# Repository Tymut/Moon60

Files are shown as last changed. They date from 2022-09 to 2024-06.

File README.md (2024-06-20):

# Moon60

---

Moon60 is is a split keyboard with 4x6 column staggered keys, 5 thumb keys and 1 extra key. This was school project related with hobby and evolved into fully functional device.

- Pro micro controller
- MX and Choc compatible, hotswap
- 128x32 OLED
- TRRS connection between sides
- Optional tenting supported by M12 screws
- Reversible PCB

**Firmware:** https://github.com/Nx0dle/qmk_firmware

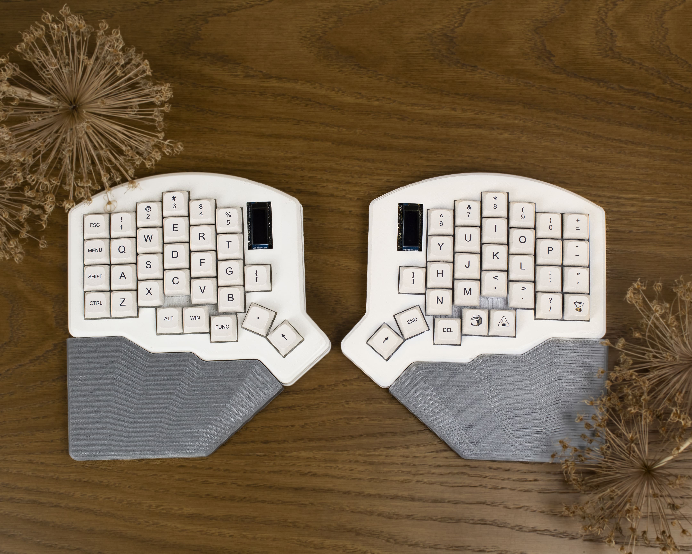
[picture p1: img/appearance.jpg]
moon60 appearance


Moon60 layout was inspired by hands scans from Ergopad (<https://github.com/pashutk/ergopad>) for matrix visualization. Scans were taken from 20 people and merged into subgroups.

Case for this keyboard is designed only for MX style switches (for now)

---

## Hand scans examples

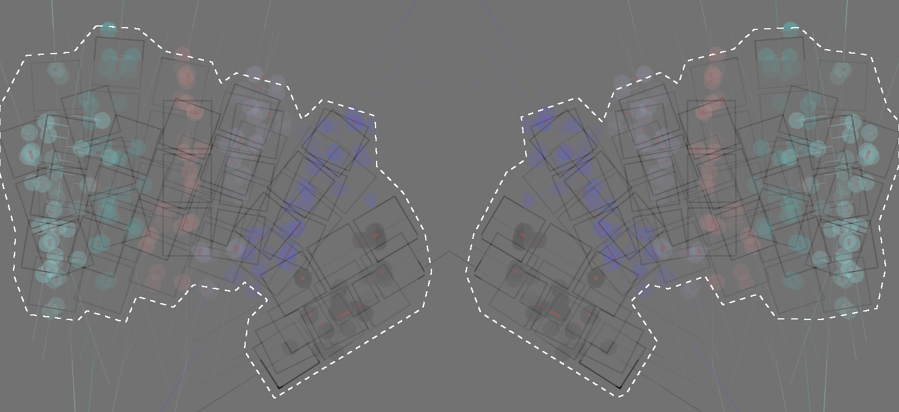
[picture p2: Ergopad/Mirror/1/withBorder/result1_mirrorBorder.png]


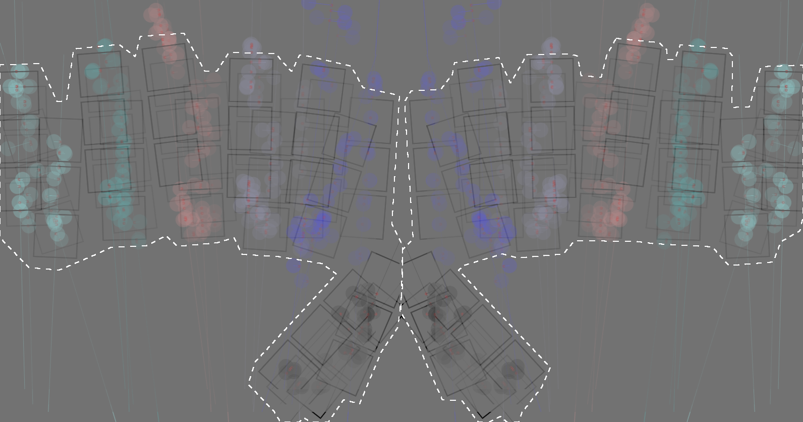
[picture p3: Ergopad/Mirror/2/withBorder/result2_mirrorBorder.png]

<br>

## CAD render

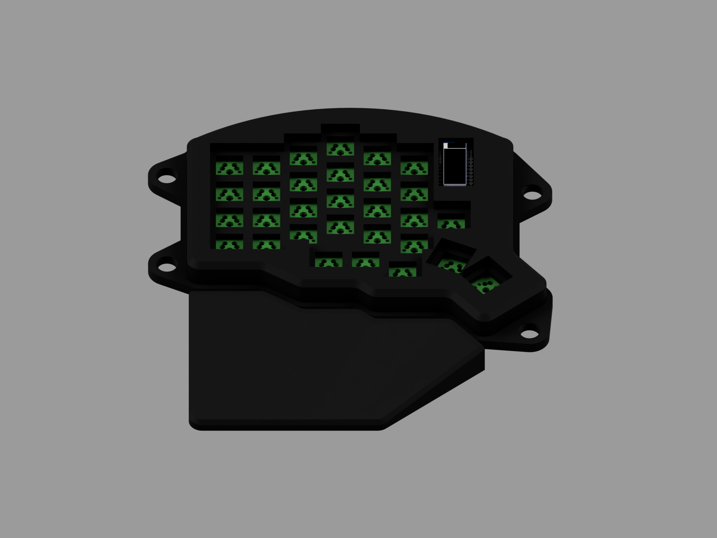
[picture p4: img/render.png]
render


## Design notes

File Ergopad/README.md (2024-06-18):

- The content of this folder is a collection of biometric data of the hands of selected people.
- The data is intended to create an average keyboard diagram.
- The collected data reflects only the right hand, therefore it will be mirrored
- The data was collected thanks to the Ergopad program (https://pashutk.com/ergopad/).
- The next step after averaging the results is to design the PCB layout and keyboard housing in the "Ergogen" generator - (https://github.com/ergogen/ergogen).
- The biometric averaged result is located in the "Result" subfolder.

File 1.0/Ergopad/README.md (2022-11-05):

# PL

- Zawartość tego folderu jest zbiorem danych biometrycznych dłoni wybranych osób.
- Dane mają na celu stworzyć uśredniony schemat klawiatury.
- Zebrane dane odzwierciedlają tylko prawą rękę dlatego wykonane zostanie odbicie lustrzane
- Dane zostały zebrane dzięki programowi Ergopad (https://pashutk.com/ergopad/).
- Kolejnym krokiem po uśrednieniu wyników jest zaprojektowanie layoutu PCB oraz obudowy klawiatury w generatorze "Ergogen" - (https://github.com/ergogen/ergogen).
- Uśredniony wynik danych biometrycznych znajduje się w podfolderze "Result".

## ENG

- The content of this folder is a collection of biometric data of the hands of selected people.
- The data is intended to create an average keyboard diagram.
- The collected data reflects only the right hand, therefore it will be mirrored
- The data was collected thanks to the Ergopad program (https://pashutk.com/ergopad/).
- The next step after averaging the results is to design the PCB layout and keyboard housing in the "Ergogen" generator - (https://github.com/ergogen/ergogen).
- The biometric averaged result is located in the "Result" subfolder.

## - Przemek Paciorek / Damian Pryszcz

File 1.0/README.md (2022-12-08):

# Opis projektu klawiatury biometrycznej - Moon60

## Autorzy: Przemek Paciorek, Damian Pryszcz

Wraz z myślą i potrzebami dzisiejszego rynku stworzyliśmy projekt wszechstronnej klawiatury dostosowywanej pod użytkownika.

Dzisiejszy świat opiera się na rozwoju technologii. W wielu jej dziedzinach używane są klawiatury, które na dłuższą metę użytkowania mogą być niebezpieczne. Najpopularniejsze klawiatury, które dominują rynek nie są tworzone z myślą o ergonomii nadgarstków. To właśnie one są najbardziej nadwyrężane w czasie użytkowania klawiatury. Niewłaściwe ułożenie nadgarstków i napięcie jakie wymusza na nas pozycja w której je układamy może wywołać np. zespół cieśni nadgarstka. Również osoby z różnymi dysfunkcjami mogą mieć problemy z użytkowaniem tej jakże potrzebnej części technologii.

W tym celu stworzyliśmy projekt nazwany bazowo **Insequor58**, lecz został on zmodyfikowany i przeniesiony do nazwy **Moon60**. Projekt stworzony został w celu poprawienia ergonomii ułożenia nadgarstków i zmniejszenia ich napięcia, jak i ułatwieniu użytkowania klawiatury przez osoby z dysfunkcjami. Projekt ma za zadanie również zapewnić użytkownikowi możliwie w jak największym stopniu dostosowanie klawiatury pod swoje potrzeby.

### Opcje dostosowania:

- Rozdzielna budowa pozwala na dostosowanie szerokości rozstawu nadgarstków.
- Ułożenie sekcji klawiszy jest zrobione w taki sposób aby zminimalizować ruch nadgarstka.
- Szeroka gama wyboru przełączników pozwala na dostosowanie wysokości jak i odczuć płynących z pisania.
- Podstawka pod nadgarstki wyrównuje napięcie dłoni i podtrzymuje je w jednym miejscu.
- "Tenting", czyli podniesienie poziome klawiatury pozwala na dostosowanie kątu pisania i co za tym idzie ustawienia nadgarstków w bardziej naturalnej pozycji.

### Wykorzystane komponenty:

- Własnoręcznie zaprojektowane PCB
- Diody półprzewodnikowe
- Arduino pro-micro
- Wyświetlacze OLED
- Przełączniki mechaniczne
- Moduły Hot-swap

Dzięki zastosowaniu odpowiedniego firmware klawiatura jest podzielona na dwie części. Wykorzystuje komunikację poprzez przewód TRRS.

"Tenting" i podpórka pod nadgarstki będą modułami magnetycznymi, a do produkcji obudowy i tych komponentów użyliśmy oprogramowania CAD CAM i drukarki 3D.

Mapa i funkcjonalność przycisków została przystosowana do jak najszybszej pracy w wielu dziedzinach. Obecnie do programowania, lecz planujemy rozwój w innych kierunkach.

W przyszłości klawiatura będzie miała możliwość przypisania dowolnych klawiszy w "locie", czyli poprzez wyświetlacz i wgrany na nią firmware, jak i również wyświetlania:

- prędkości pisania
- poziomu ekploatacji komponentów komputera
- efektów graficznych

Planujemy dalszy złożony rozwój projektu i liczymy na liczne rezultaty.

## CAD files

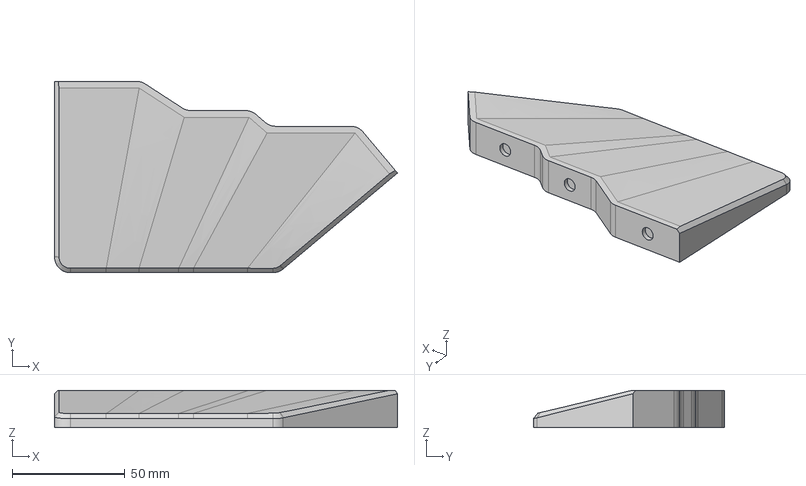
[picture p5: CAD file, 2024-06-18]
case/MX/wirstRest.step
152.3 x 85.0 x 16.6 mm

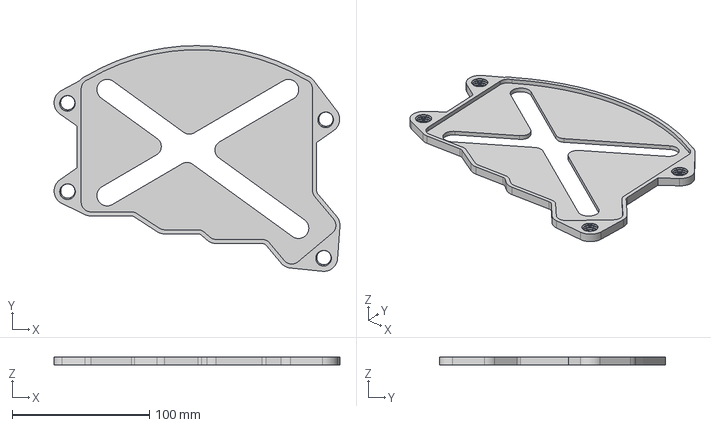
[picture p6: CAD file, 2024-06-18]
case/MX/tentingLeft.step
208.2 x 164.4 x 6.00 mm

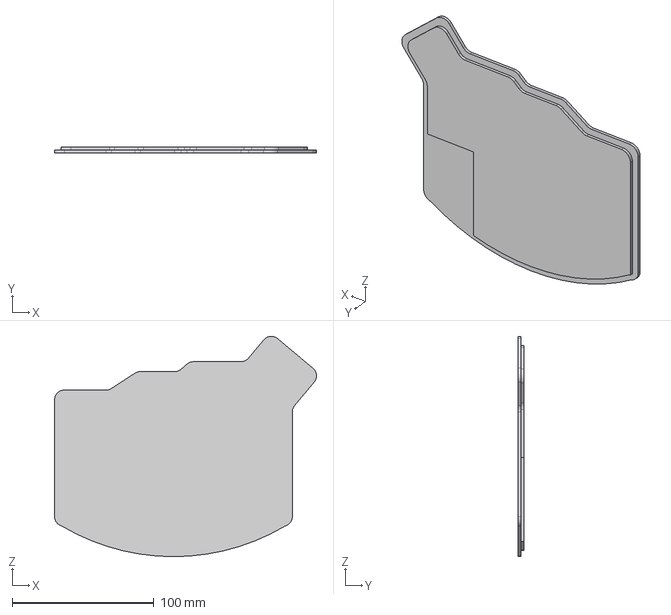
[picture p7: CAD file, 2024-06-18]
case/MX/bottom.step
185.0 x 4.00 x 155.6 mm

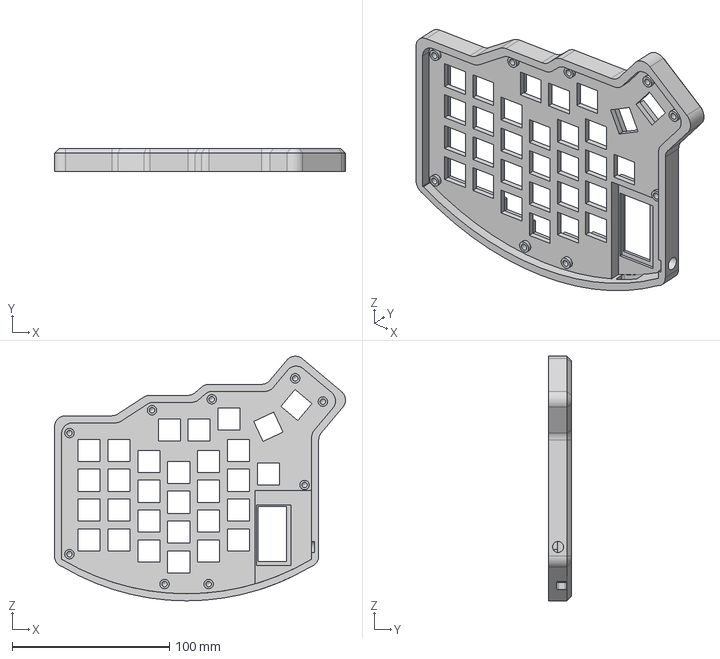
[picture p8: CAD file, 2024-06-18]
case/MX/top.step
185.0 x 14.6 x 155.6 mm

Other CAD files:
case/MX/tentingRight.step

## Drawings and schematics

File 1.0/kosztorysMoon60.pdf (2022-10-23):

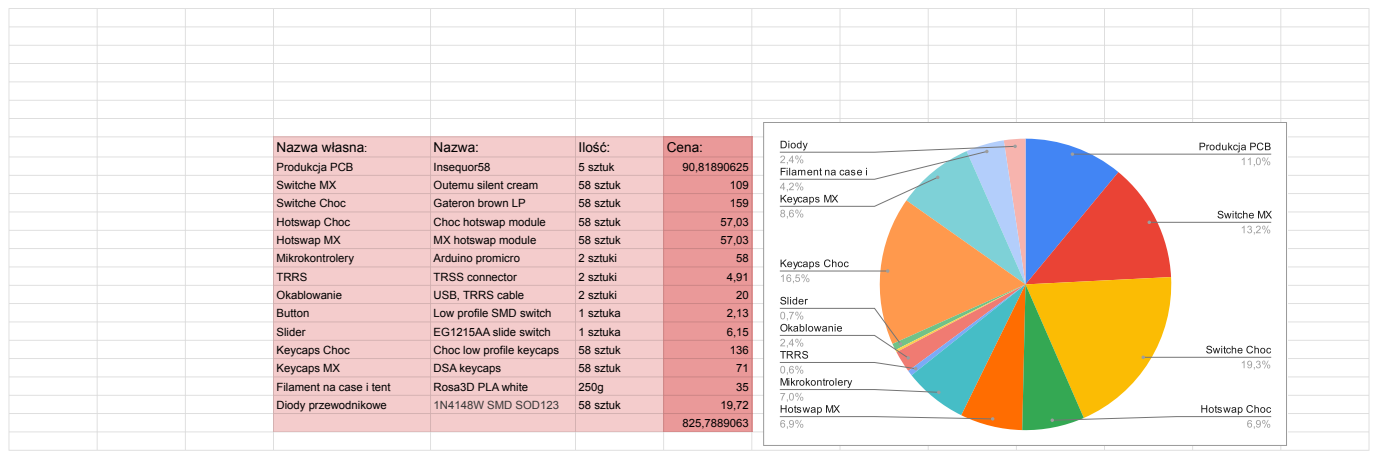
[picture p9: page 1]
Nazwa własna:; Nazwa:; Ilość:; Cena:; Produkcja PCB; Insequor58; 5 sztuk; Switche MX; Outemu silent cream; 58 sztuk; Switche Choc; Gateron brown LP; Hotswap Choc; Choc hotswap module; Hotswap MX; MX hotswap module; Mikrokontrolery; Arduino promicro; 2 sztuki; TRRS; TRSS connector; Okablowanie; USB, TRRS cable; Button; Low profile SMD switch; 1 sztuka; Slider; EG1215AA slide switch; Keycaps Choc; Choc low profile keycaps; Keycaps MX; DSA keycaps; Filament na case i tent; Rosa3D PLA white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

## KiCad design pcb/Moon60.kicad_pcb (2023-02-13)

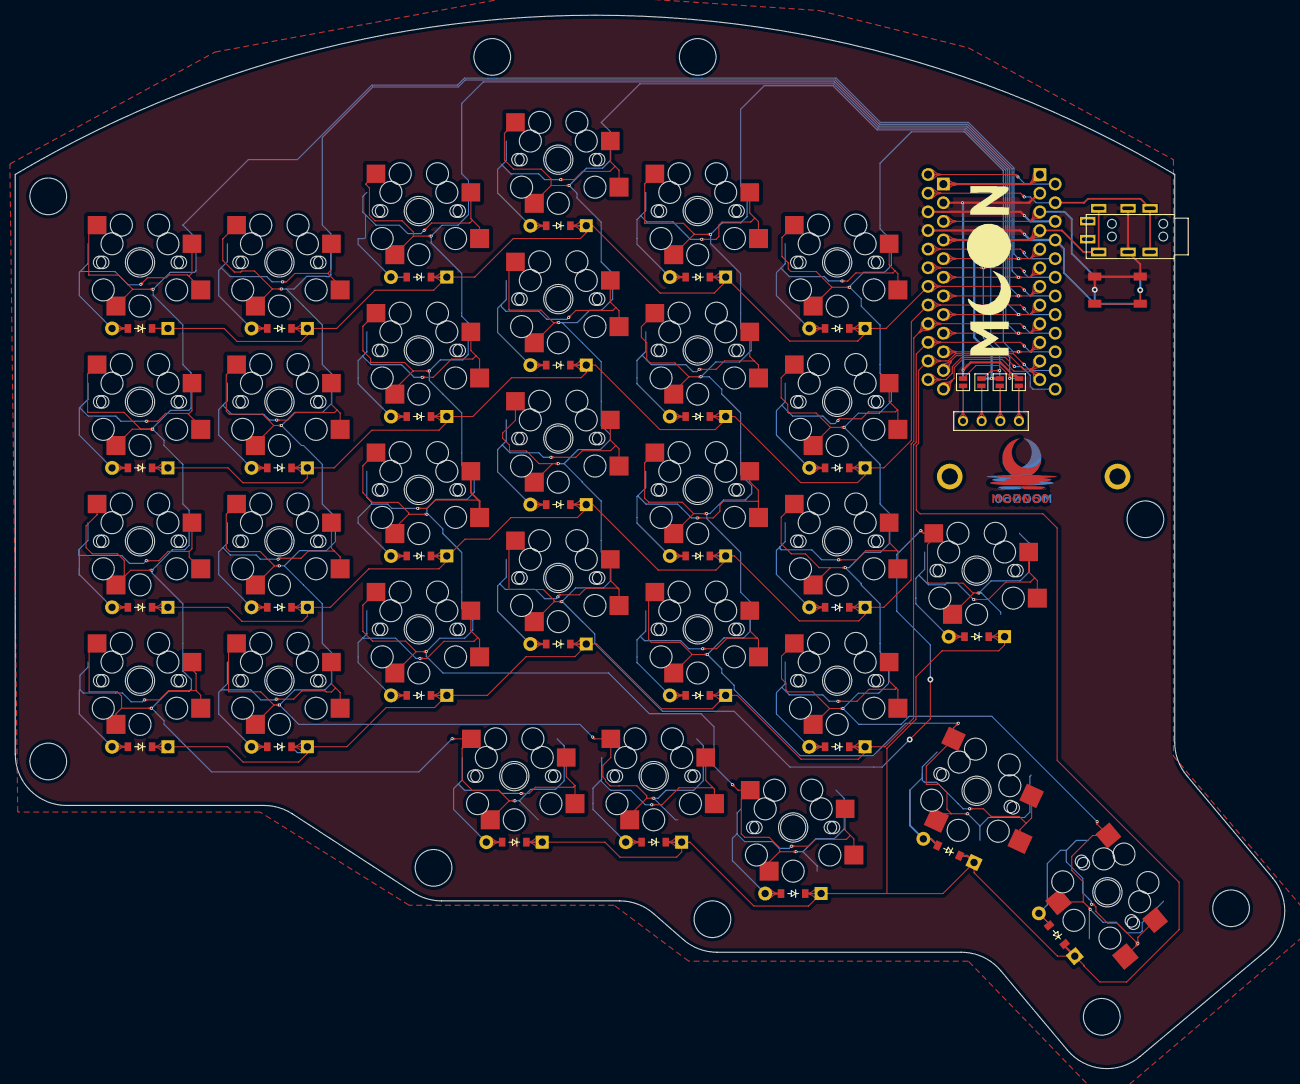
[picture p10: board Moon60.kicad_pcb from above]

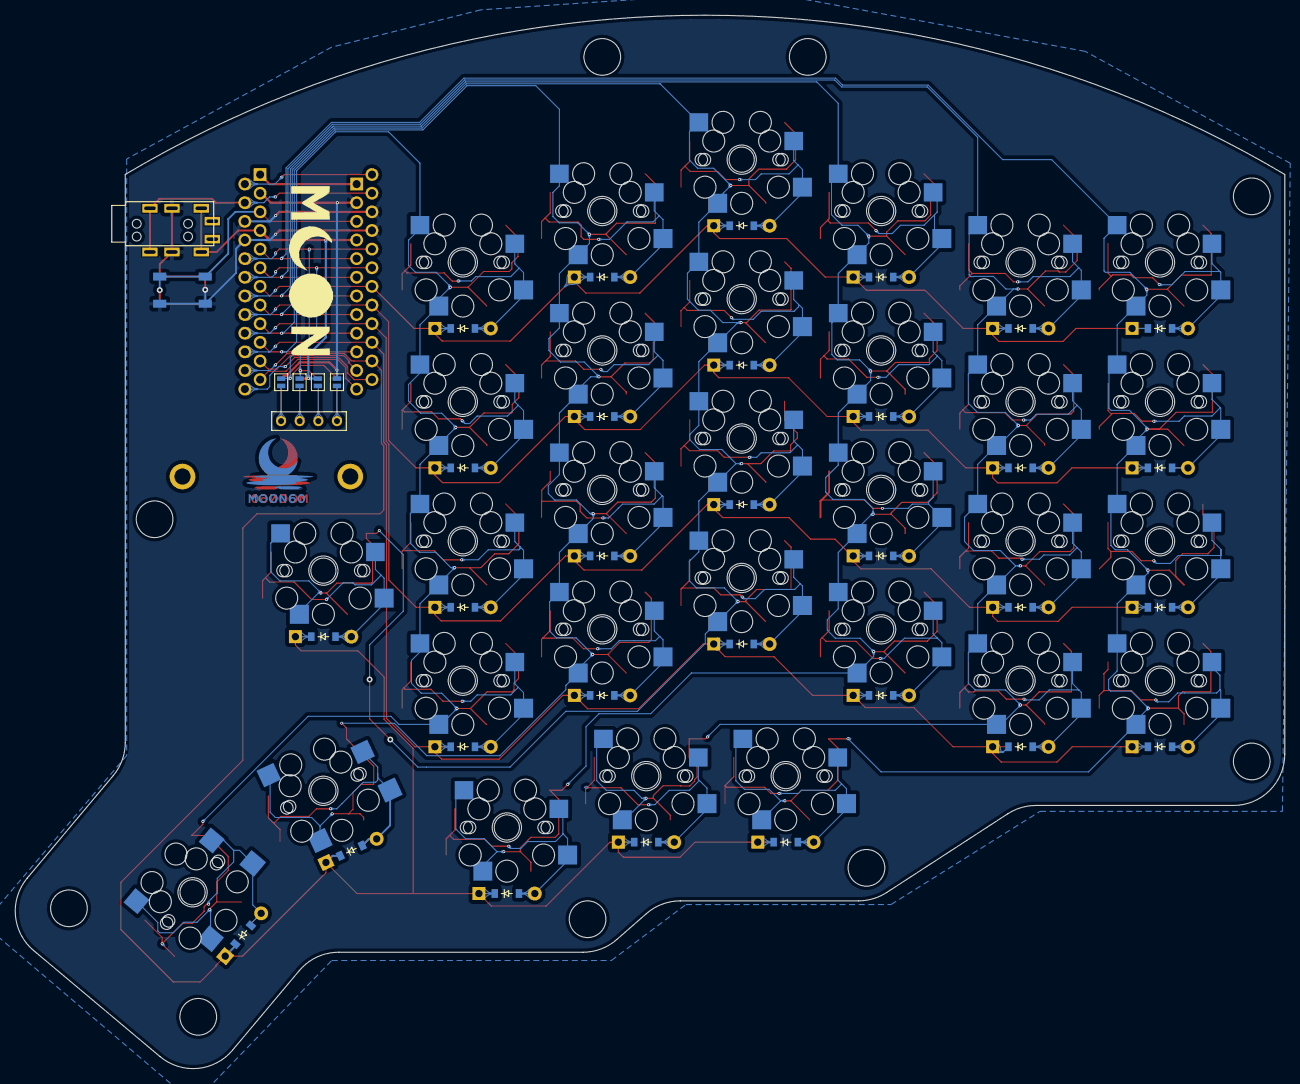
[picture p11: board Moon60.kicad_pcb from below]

Board: 2 copper layers, 173.0 x 143.5 mm, 104 parts (33 on the bottom side), 22 nets.

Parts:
B1, B1#2: SW_TACT_ALPS_SKQGABE010
D1, D2, D3, D4, D5, D6, D7, D8, D9, D10, D11, D12, D13, D14, D15, D16, D17, D18, D19, D20, D21, D22, D23, D24, D25, D26, D27, D28, D29, D30: ComboDiode
J2: 4PIN; MJ-4PP-9
J3: OLED; OLED_4Pin
JP1, JP2, JP3, JP4, JP5, JP6, JP7, JP8: Jumper
MCU1, MCU2: ProMicro
S1, S3, S5, S7, S9, S11, S13, S15, S17, S19, S21, S23, S25, S27, S29, S31, S33, S35, S37, S39, S41, S43, S45, S47, S49, S51, S53, S55, S57, S59: PG1350
S2, S4, S6, S8, S10, S12, S14, S16, S18, S20, S22, S24, S26, S28, S30, S32, S34, S36, S38, S40, S42, S44, S46, S48, S50, S52, S54, S56, S58, S60: MX

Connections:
GND: B1.1, B1#2.1, J2.2, JP1.2, JP5.2, MCU1.2, MCU1.15, MCU1.16, MCU2.2, MCU2.15, MCU2.16
P0: J2.3, MCU1.14, MCU2.14
P1: MCU1.13, MCU2.13
P2: JP4.2, JP8.2, MCU1.17, MCU2.17
P3: JP3.2, JP7.2, MCU1.18, MCU2.18
P4: D4.1, D4.2, D8.1, D8.2, D12.1, D12.2, D16.1, D16.2, D20.1, D20.2, D24.1, D24.2, MCU1.19, MCU2.19, S7.2, S8.1, S15.2, S16.1, S23.2, S24.1, S31.2, S32.1, S39.2, S40.1, S47.2, S48.1
P5: D3.1, D3.2, D7.1, D7.2, D11.1, D11.2, D15.1, D15.2, D19.1, D19.2, D23.1, D23.2, MCU1.20, MCU2.20, S5.2, S6.1, S13.2, S14.1, S21.2, S22.1, S29.2, S30.1, S37.2, S38.1, S45.2, S46.1
P6: D2.1, D2.2, D6.1, D6.2, D10.1, D10.2, D14.1, D14.2, D18.1, D18.2, D22.1, D22.2, MCU1.21, MCU2.21, S3.2, S4.1, S11.2, S12.1, S19.2, S20.1, S27.2, S28.1, S35.2, S36.1, S43.2, S44.1
P7: D1.1, D1.2, D5.1, D5.2, D9.1, D9.2, D13.1, D13.2, D17.1, D17.2, D21.1, D21.2, MCU1.22, MCU2.22, S1.2, S2.1, S9.2, S10.1, S17.2, S18.1, S25.2, S26.1, S33.2, S34.1, S41.2, S42.1
P8: D25.1, D25.2, D26.1, D26.2, D27.1, D27.2, D28.1, D28.2, D29.1, D29.2, D30.1, D30.2, MCU1.23, MCU2.23, S49.2, S50.1, S51.2, S52.1, S53.2, S54.1, S55.2, S56.1, S57.2, S58.1, S59.2, S60.1
P9: MCU1.24, MCU2.24
P10: MCU1.12, MCU2.12
P14: MCU1.10, MCU2.10, S41.1, S42.2, S43.1, S44.2, S45.1, S46.2, S47.1, S48.2, S59.1, S60.2
P15: MCU1.9, MCU2.9, S33.1, S34.2, S35.1, S36.2, S37.1, S38.2, S39.1, S40.2, S57.1, S58.2
P16: MCU1.11, MCU2.11
P18: MCU1.8, MCU2.8, S25.1, S26.2, S27.1, S28.2, S29.1, S30.2, S31.1, S32.2, S55.1, S56.2
P19: MCU1.7, MCU2.7, S17.1, S18.2, S19.1, S20.2, S21.1, S22.2, S23.1, S24.2, S53.1, S54.2
P20: MCU1.6, MCU2.6, S9.1, S10.2, S11.1, S12.2, S13.1, S14.2, S15.1, S16.2, S51.1, S52.2
P21: MCU1.5, MCU2.5, S1.1, S2.2, S3.1, S4.2, S5.1, S6.2, S7.1, S8.2, S49.1, S50.2
RAW: MCU1.1, MCU2.1
RST: B1.2, B1#2.2, MCU1.3, MCU2.3
VCC: J2.1, JP2.2, JP6.2, MCU1.4, MCU2.4

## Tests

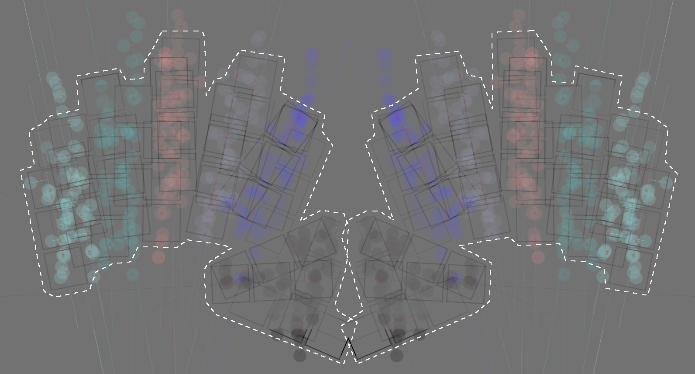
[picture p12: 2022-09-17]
Ergopad/Mirror/3/withBorder/result3_mirrorBorder.png

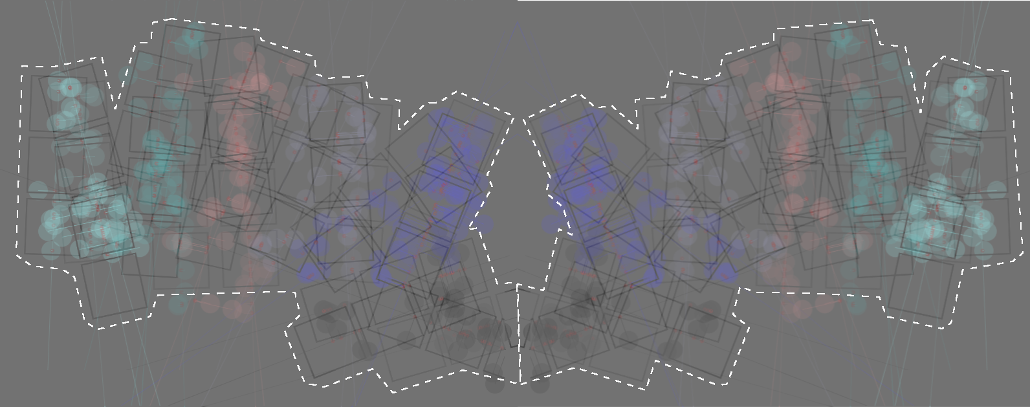
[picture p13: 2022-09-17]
Ergopad/Mirror/4/withBorder/result4_mirrorBorder.png

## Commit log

2022-10-14 Ver0.2 (Case-rebuild, .dfx-sorted, definition-added)
2022-10-15 Ver0.5 (footprints-rebuild, nets-added)
2022-10-16 v0.6.1 (outlines-scaled_up, plate_fixed)
2022-10-20 v0.7 (mounting_holes-fixed, wireless-BETA)
2022-10-23 v9.2 (plateCutOLD-optional)
2022-10-23 v0.9.2 (switch_slots-update)
2022-10-29 Insequor58 v1.0 stableAssembly
    Footprints-positionsFixed, added optional switch, mounting-fixed
2022-10-29 KiCad filesAdded
    [insequor58.sch, insequor58top.kicad_pcb, insequor58tray.kicad_pcb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]
2022-11-01 KiCad update
2022-11-02 KiCad filesUpdate
    [insequor58.sch, insequor58TOPMOUNT.kicad_sch, insequor58tray.kicad_pcb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]
2022-11-02 KiCad files update
2022-11-03 Dodanie schematu Bottom Case w formacie pdf
2022-11-04 Moon60 name update
    [insequor58≈Moon60.kicad_pcb, insequor58≈Moon60.kicad_sch, sizing_help.kicad_pcb]
2022-11-05 Files update
    [plate.stl, plateTOP.stl, plateTRAY.stl]
2022-11-10 v1.0.5 (Final PCB)
2022-11-10 v1.0.6 (Plate finishing touches)
2022-11-10 KiCad moon60 footprints added
2022-11-27 v1.0.6 (Plate screw holes fixed)
2022-11-27 Plate update
    [plate.stl]
2022-11-27 v1.0.7 (plate.stl adjust)
2022-11-27 v1.0.8 (experimental plate thickness adjust)
2022-12-11 Spliting project to 1.0 and 2.0
    [circle_top.dxf, cutout.dxf, demo.dxf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]
2022-12-22 ergogen exports update
    [moon60Top.kicad_pcb, moon60Tray.kicad_pcb, plateTOP.kicad_pcb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]
2023-01-10 1.0 PCB splitted to I2C and non I2C ver (building)
    [insequor58≈Moon60.kicad_sch, insequor58≈Moon60I2Cold.kicad_pcb, insequor58≈Moon60NOi2c.kicad_pcb]
2023-01-11 1.0 WRONG PCB setted
    [insequor58≈Moon60.kicad_sch, insequor58≈Moon60I2Cold.kicad_pcb]
2023-01-11 Tenting supports model added
    [higherSupport85mm_.stl, lowerSupport18.5mm.stl]
2023-01-11 3DP arround PCB files added
    [higherSupport85mm_.stl, lowerSupport18.5mm.stl, plate.stl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]
2023-01-12 1.0 PCB quick fix
    [insequor58≈Moon60NOi2c.kicad_pcb]
2023-01-27 top frame and bottom case sketches added ~ metric
2023-01-27 added 0.5mm offsets to case and frame
2023-02-04 mcu reversible and plate offset sketch
2023-02-04 footprints minor changes
2023-02-07 added top frame components cut
2023-02-13 PCB manufacturing
    [insequor58≈Moon60NOi2c-B_Cu.gbr, insequor58≈Moon60NOi2c-B_Mask.gbr, insequor58≈Moon60NOi2c-B_Paste.gbr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]
2023-02-17 merging from PC
    [bottom_case_walls.dxf, circle_top.dxf, circle_top_offset.dxf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]
2023-03-02 Major changes for final split PCB
2023-03-04 re-merging items
    [bottom_case_walls.dxf, circle_top.dxf, circle_top_offset.dxf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]
2023-05-11 kicad layers scan + minor changes to keymap
    [insequor58≈Moon60Noi2c.kicad_sch]
2024-06-18 repository reorganize - remove old files
    [Moon60.kicad_pcb, Moon60.kicad_sch, bottom.step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]
